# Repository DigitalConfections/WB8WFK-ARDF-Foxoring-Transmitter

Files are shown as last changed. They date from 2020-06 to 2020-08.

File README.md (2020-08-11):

<h1>WB8WFK ARDF Foxoring Transmitter</h1>
<p>This is a simple, inexpensive, transmitter and controller for conducting ARDF Foxoring competitions and for demonstrating ARDF principles. The software project is an Arduino script that builds for and runs on most Arduino-like products, including <a href="https://www.adafruit.com/product/2590">AdaFruit's Metro Mini 328</a>, or <a href="https://www.sparkfun.com/products/11113">SparkFun's Arduino Pro Mini 328</a>, and most any board with an ATMEGA328P processor.</p>

<p>Controller support for all the common ARDF competition formats is provided: Classic, Sprint, and Foxoring.</p>

<h2>Software</h2>
<p>The software is a proper Arduino script that will open and build without warnings or errors in Arduino IDE version 1.8.12 and later. It has also been shown to work with the online <a href="https://create.arduino.cc/editor">Arduino Web Editor</a>. The Arduino IDE can be used to program a device that contains a compatible bootloader. Most Arduino products ship with a bootloader pre-installed.</p>

<p>After being programmed, the controller can be configured via a serial port on the board. An Arduino board that includes a USB-to-Serial converter will allow you to configure the controller with a simple USB cable (standard to micro) connected between a USB port on your computer to one on the Arduino board. Less sophisticated Arduino boards lacking a USB-to-Serial converter will require a special FTDI cable like <a href="https://www.adafruit.com/product/70">AdaFruit's FTDI Serial TTL-232 USB Cable</a>, or <a href="https://www.sparkfun.com/products/9718">SparkFun's FTDI Cable 5V</a>.</p>

<p>The fox-controller software provides an output pin for controlling a transmitter for sending Morse code characters (high = key down; low = key up) and a separate pin that sends the Morse code as audio tones that can be used to drive a speaker. The controller can also provide a sequence of starting-tones prompting competitors to begin a competition, and can thus serve as an electronic starting "gun" for use in ARDF events.</p>

<h3>Serial Commands</h3>
<p>The fox-controller serial interface operates at 57600 baud, and can be accessed using any serial TTY interface program such as PuTTY or Arduino's own Serial Monitor tool. It provides a command prompt > indicating that it is ready to receive any of the following commands.
</p>

<pre><p><b>> CAL [num]</b>  <= <i>* Sets the clock calibration for precise timing</i><br>
<b>> CAL</b>  <= <i>Displays the clock calibration setting</i><br>
<b>> DIP [val]</b>  <= <i>* Sets the competition format, overriding the DIP switch settings</i><br>
<b>> DIP</b>  <= <i>Displays the competition format setting</i><br>
<b>> FAC</b>  <= <i>Sets saved EEPROM values to their original defaults</i><br>
<b>> GO</b>  <= <i>Starts operation from zero seconds, equivalent to pressing the sync button</i><br>
<b>> ID [string]</b>  <= <i>* Sets the callsign that gets sent</i><br>
<b>> ID</b>  <= <i>Displays the saved callsign setting</i><br>
<b>> LED [on|off]</b>  <= <i>* Turns on/off LED pin</i><br>
<b>> LED</b>  <= <i>Displays the LED pin setting</i><br>
<b>> RST</b>  <= <i>Resets the processor</i><br>
<b>> SPD ID [num]</b>  <= <i>* Sets the ID code speed in WPM</i><br>
<b>> SPD</b>  <= <i>Displays the ID code speed setting</i><br>
<b>> STA [on|off]</b>  <= <i>* Turns on/off the starting tones function</i><br>
<b>> STA</b>  <= <i>Displays the starting tones setting</i><br>
<b>> TEM</b>  <= <i>Displays the processor's temperature in C</i><br>
<b>> TXE [on|off]</b>  <= <i>* Turns on/off the transmitter</i><br>
<b>> TXE</b>  <= <i>Displays the transmitter setting</i><br>
<b>> VER</b>  <= <i>Displays the software version number</i></p></pre>

<p>* These values get stored to EEPROM and are retained between power cycles. </p>
<h2>Hardware</h2>
<p>Look in the Hardware folder for all hardware-related documents</p>
<h3>Pinout</h3>

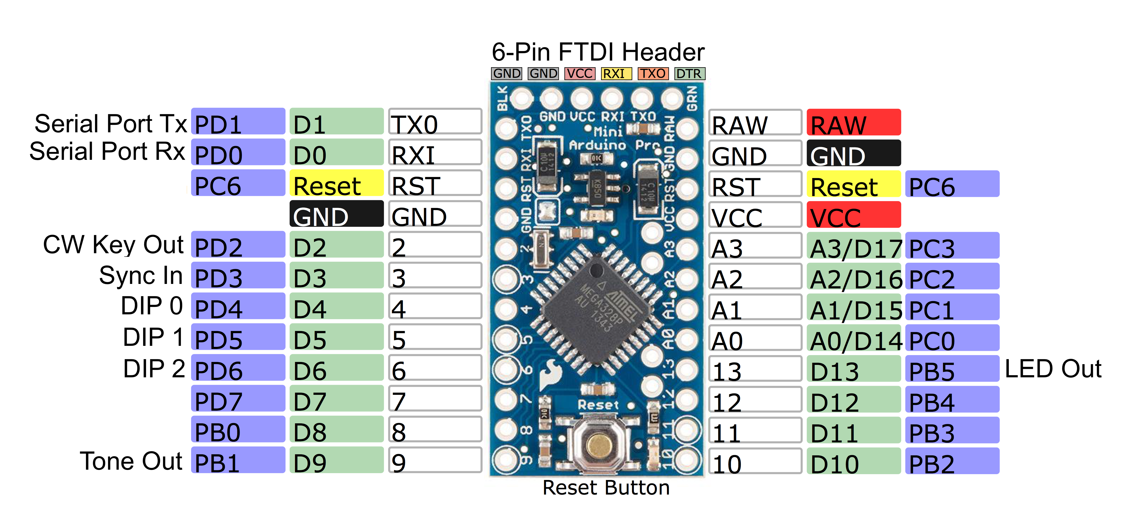
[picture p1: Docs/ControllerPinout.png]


<pre><p><b>PB1 - Board Pin 9  (Output)</b> <= Audio Out (=Gnd when no tone)<br>
<b>PB5 - Board Pin 13 (Output)</b> <= LED On=VCC<br>
<b>PD2 - Board Pin 2  (Output)</b> <= Key/PTT On=VCC<br>
<b>PD3 - Board Pin 3  (Input)</b>  <= Synchronize (mom. switch to Gnd)<br>
<b>PD4 - Board Pin 4  (Input)</b> <= DIP Switch Bit 0 (switch to Gnd)<br>
<b>PD5 - Board Pin 5  (Input)</b> <= DIP Switch Bit 1 (switch to Gnd)<br>
<b>PD6 - Board Pin 6  (Input)</b> <= DIP Switch Bit 2 (switch to Gnd)</p></pre>

<h2>Usage</h2>
<p>The transmitter can be configured using the serial port, or using the DIP switch and sync-button hardware interface. Only a subset of the possible configurations is available when using only the hardware interface. Configuring the DIP setting with a serial port command to anything but CLASSIC BEACON (zero) will disable the hardware DIP switch.</p>
<p>In the table below, default settings are shown in <b>boldface</b>. Serial command arguments may be abbreviated using the first letter of the word. For example: <b>> DIP CLASSIC BEACON</b> can be shortened to <b>> DIP C B</b>.</p>
<p>
    <table>
        <tr>
            <th>Function</th>
            <th>Software Commands</th>
            <th>Hardware Settings</th>
        </tr>
        <tr>
            <td>Homing Beacon</td>
            <td><b>> DIP CLASSIC BEACON</b><br>[Note: the DIP switch must also be set to 0-0-0]</td>
            <td>DIP = 0-0-0</td>
        </tr>
        <tr>
            <td>Classic Fox#1</td>
            <td>> DIP CLASSIC 1<br>> GO</td>
            <td>DIP = 0-0-1<br>Sync to start</td>
        </tr>
        <tr>
            <td>Classic Fox#2</td>
            <td>> DIP CLASSIC 2<br>> GO</td>
            <td>DIP = 0-1-0<br>Sync to start</td>
        </tr>
        <tr>
            <td>Classic Fox#3</td>
            <td>> DIP CLASSIC 3<br>> GO</td>
            <td>DIP = 0-1-1<br>Sync to start</td>
        </tr>
        <tr>
            <td>Classic Fox#4</td>
            <td>> DIP CLASSIC 4<br>> GO</td>
            <td>DIP = 1-0-0<br>Sync to start</td>
        </tr>
        <tr>
            <td>Classic Fox#5</td>
            <td>> DIP CLASSIC 5<br>> GO</td>
            <td>DIP = 1-0-1<br>Sync to start</td>
        </tr>
        <tr>
            <td>Classic Demonstration</td>
            <td>> DIP CLASSIC DEMO</td>
            <td>DIP = 1-1-0</td>
        </tr>
        <tr>
            <td>Foxoring</td>
            <td>> DIP FOXORING</td>
            <td>DIP = 1-1-1</td>
        </tr>
        <tr>
            <td>Spectator Beacon</td>
            <td>> DIP FOXORING SPEC</td>
            <td>N/A</td>
        </tr>
        <tr>
            <td>Sprint Fox Slow #1</td>
            <td>> DIP SPRINT S1</td>
            <td>N/A</td>
        </tr>
        <tr>
            <td>Sprint Fox Slow #2</td>
            <td>> DIP SPRINT S2</td>
            <td>N/A</td>
        </tr>
        <tr>
            <td>Sprint Fox Slow #3</td>
            <td>> DIP SPRINT S3</td>
            <td>N/A</td>
        </tr>
        <tr>
            <td>Sprint Fox Slow #4</td>
            <td>> DIP SPRINT S4</td>
            <td>N/A</td>
        </tr>
        <tr>
            <td>Sprint Fox Slow #5</td>
            <td>> DIP SPRINT S5</td>
            <td>N/A</td>
        </tr>
        <tr>
            <td>Sprint Fox Fast #1</td>
            <td>> DIP SPRINT F1</td>
            <td>N/A</td>
        </tr>
        <tr>
            <td>Sprint Fox Fast #2</td>
            <td>> DIP SPRINT F2</td>
            <td>N/A</td>
        </tr>
        <tr>
            <td>Sprint Fox Fast #3</td>
            <td>> DIP SPRINT F3</td>
            <td>N/A</td>
        </tr>
        <tr>
            <td>Sprint Fox Fast #4</td>
            <td>> DIP SPRINT F4</td>
            <td>N/A</td>
        </tr>
        <tr>
            <td>Sprint Fox Fast #5</td>
            <td>> DIP SPRINT F5</td>
            <td>N/A</td>
        </tr>
        <tr>
            <td>Sprint Demonstration</td>
            <td>> DIP SPRINT DEMO</td>
            <td>N/A</td>
        </tr>
        <tr>
            <td>Starting Tones Generator</td>
            <td>> DIP [any of the above]<br><b>> STA ON</b><br>> GO</td>
            <td>N/A</td>
        </tr>
        <tr>
            <td>Synchronize</td>
            <td>> GO</td>
            <td>Pull sync pin low for at least 1 second<br>Allow sync pin to rise<br>[Must happen within 1 fox cycle after power-on]</td>
        </tr>
    </table>
</p>

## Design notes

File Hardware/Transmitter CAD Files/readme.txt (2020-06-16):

files in this zip are:

1. readme.txt  this file.
2. case_lid.stl the lid for the transmitter case.
3. bottom_half.stl the bottom main part of the case.
4. 80mbase.stl the sub chaassis that the PCB mounts on. Glue inside case.
5. audio_jack_holder.stl  a bracket to hold optional audio jack for tone outputs.
6. 9vbattery_adaptor.stl a test adaptor for testbench testing with a powersupply.

All units are mm

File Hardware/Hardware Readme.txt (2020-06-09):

Boards were ordered from JLCPCP https://jlcpcb.com/

It's important to set up an account and login before uploading the zip file. Failure to do so could result in losing the file from your cart.

Just log in, upload the zip as is (they check the files instantly), select some options and the number of boards you want.

Typical cost for these boards is $25 / 15 boards with no discounts applied.

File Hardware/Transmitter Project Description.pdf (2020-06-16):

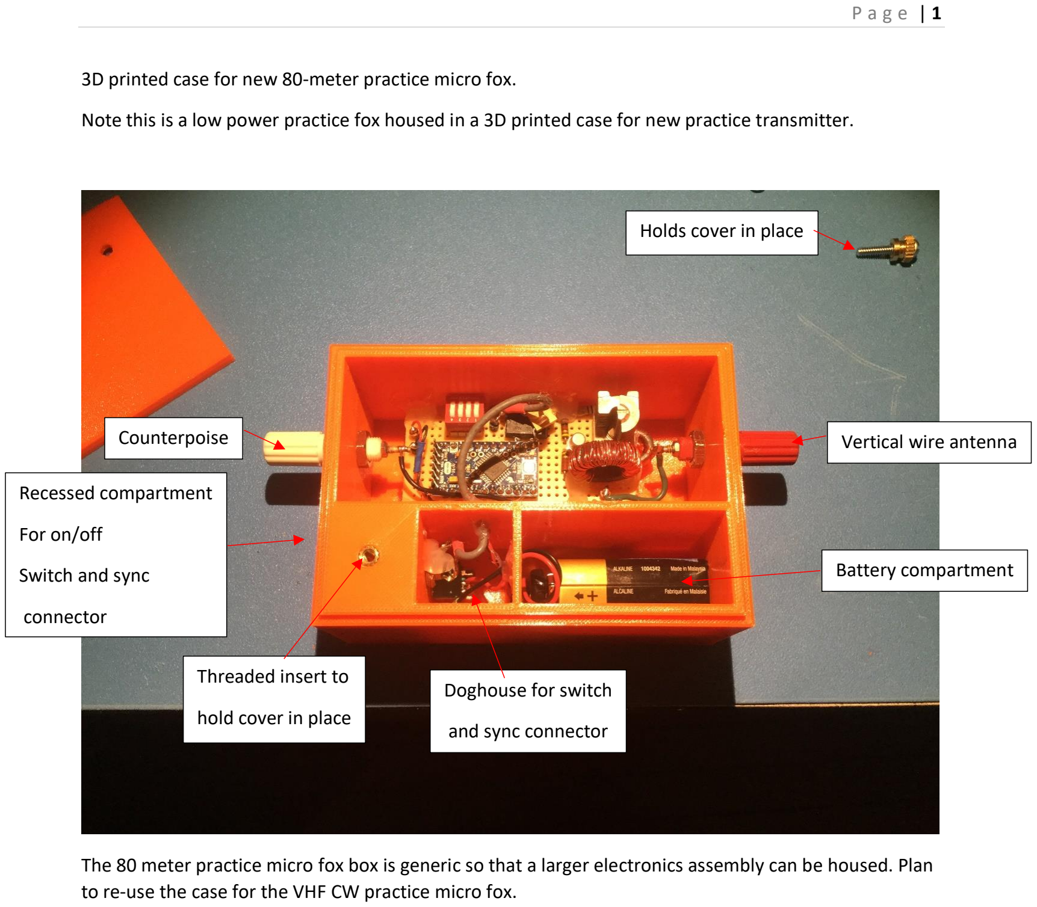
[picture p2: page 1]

P a g e | 1

3D printed case for new 80-meter practice micro fox.

Note this is a low power practice fox housed in a 3D printed case for new practice transmitter.

The 80 meter practice micro fox box is generic so that a larger electronics assembly can be housed. Plan to re-use the case for the VHF CW practice micro fox.

Counterpoise | Vertical wire antenna

Battery compartment

Doghouse for switch

and sync connector

Recessed compartment

For on/off

Switch and sync

connector

Threaded insert to

hold cover in place

Holds cover in place

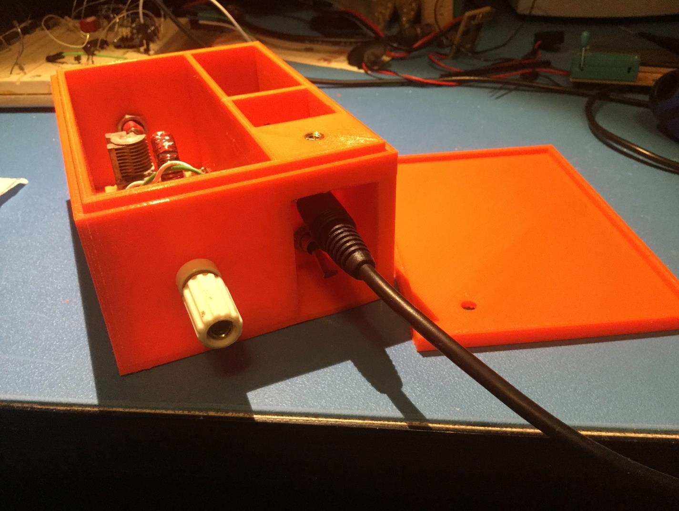
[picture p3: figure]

Here the sync cable is plugged in. Plan to make a 3D cover to slide in and cover the recessed on/off switch and sync compartment

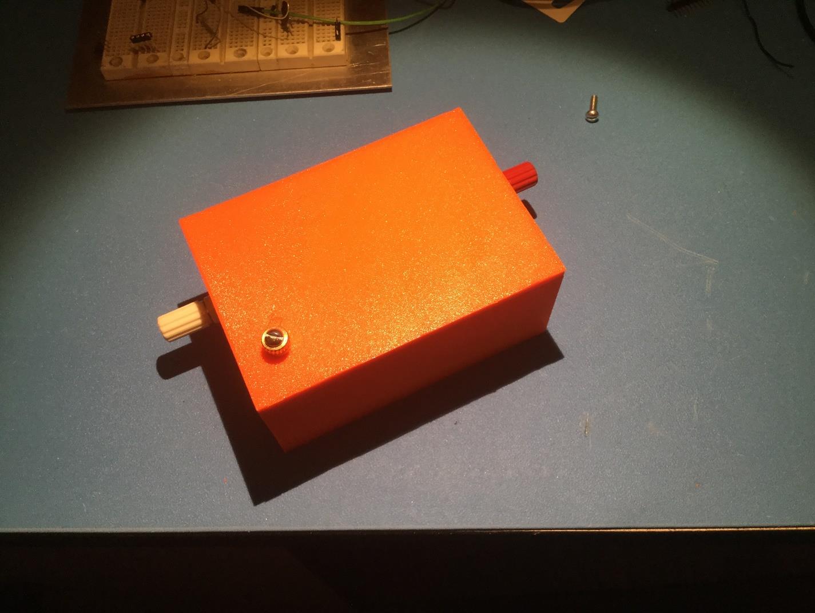
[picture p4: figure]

Here the cover is in place.

The fox Arduino code does the following based on dip switch setting

- Standard 5 transmitter MOE, MOI, MOS, MOH and MO5 one minute on synced via sync connector.
- MO homing beacon mode.
- Practice mode where it cycles through MOE, MOI, MOS, MOH and MO5 from single transmitter for a one transmitter practice session.
- Fox O (beep - beep) mode with one-minute ID.
- Sync input is not a CPU reset its accomplished using an I/O line that checked after power up and after sync operation it no longer checked again until next power cycle. Prevents false resets due to ESD events if a processor reset line is used for sync. ESD is an issue in NM due to our exceptionally low humidity.

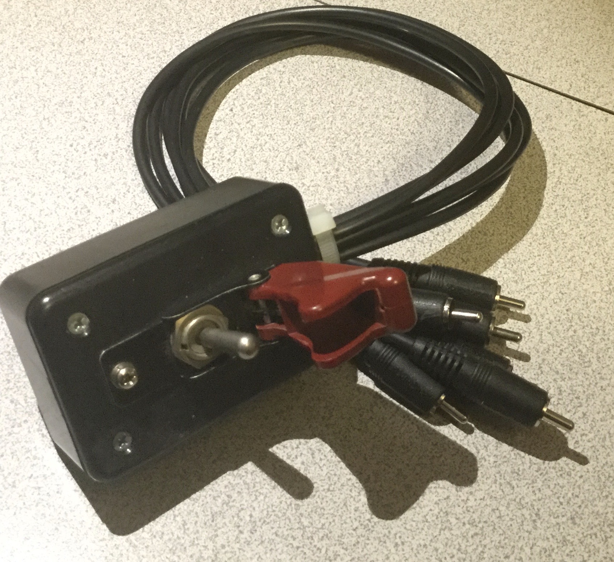
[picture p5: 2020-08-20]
Hardware/sync_switch.jpg

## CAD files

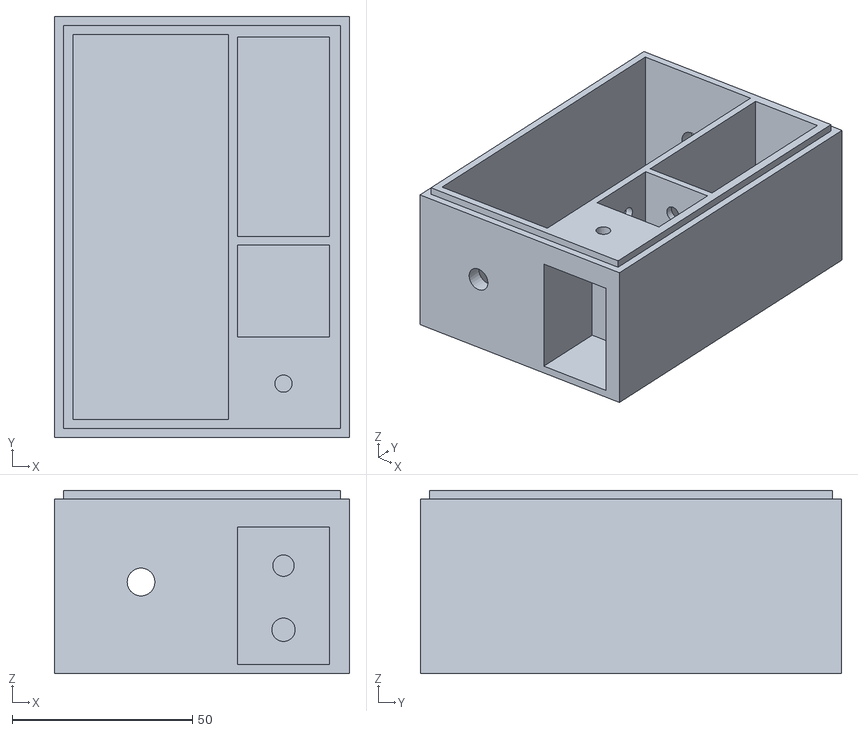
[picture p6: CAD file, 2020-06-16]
Hardware/Transmitter CAD Files/bottom_half.stl
81.8 x 116.8 x 50.8

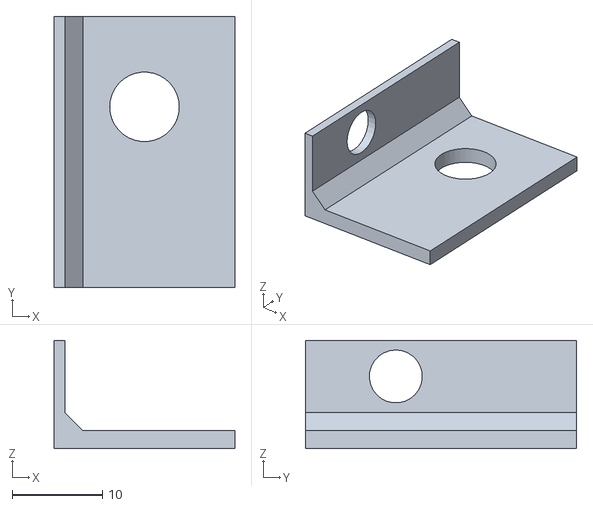
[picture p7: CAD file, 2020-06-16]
Hardware/Transmitter CAD Files/audio_jack_holder.stl
20.0 x 30.0 x 12.0

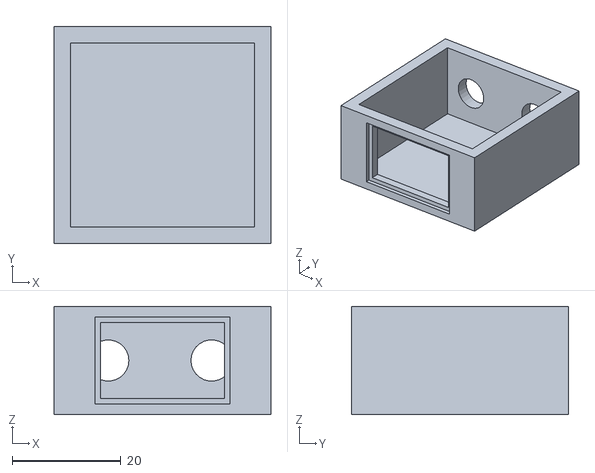
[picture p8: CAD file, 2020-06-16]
Hardware/Transmitter CAD Files/9vbattery_adaptor.stl
40.0 x 40.0 x 20.0

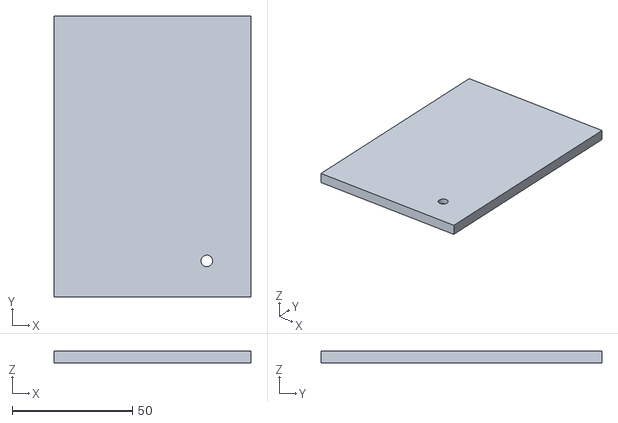
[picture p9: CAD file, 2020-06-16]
Hardware/Transmitter CAD Files/case_lid.stl
81.8 x 116.8 x 5.08

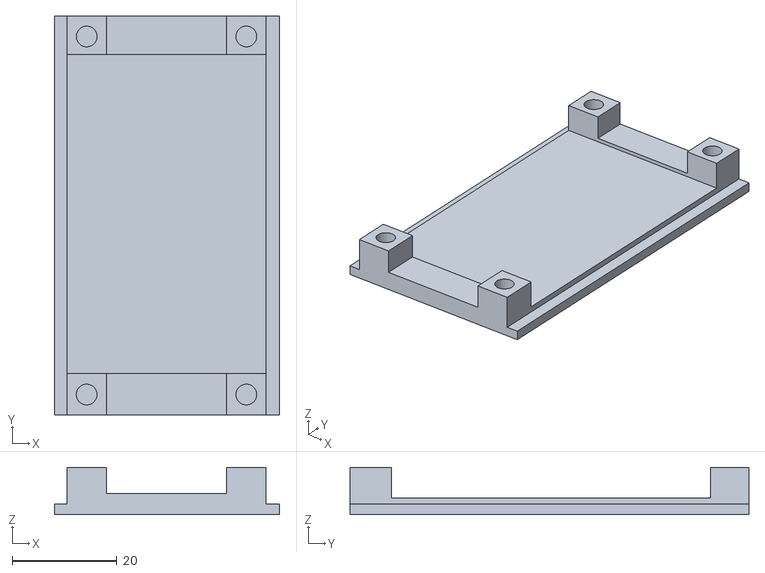
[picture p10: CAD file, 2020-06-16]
Hardware/Transmitter CAD Files/80mbase.stl
43.0 x 76.2 x 9.00

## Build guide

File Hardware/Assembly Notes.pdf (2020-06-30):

## Section 1: Reference graphics

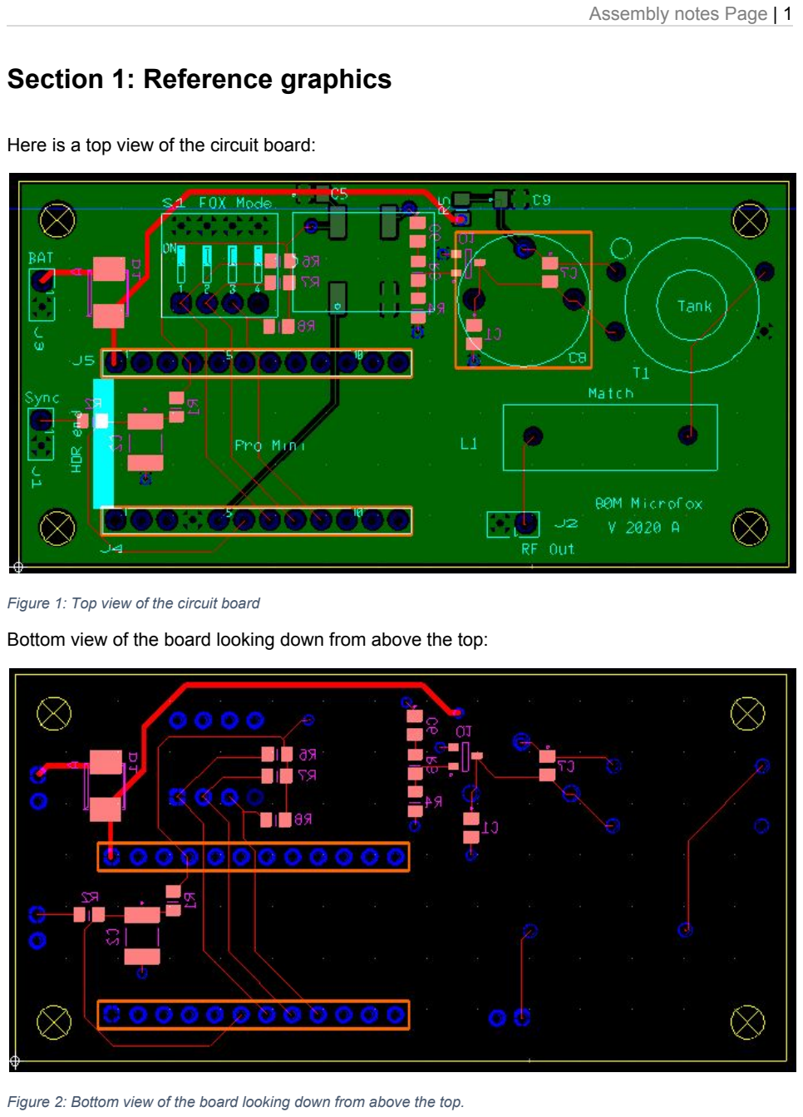
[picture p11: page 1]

Assembly notes Page | 1

Here is a top view of the circuit board:

Figure 1: Top view of the circuit board
Bottom view of the board looking down from above the top:

Figure 2: Bottom view of the board looking down from above the top.

Photo of the bottom of the board showing connection to tone output. This is a feature that was added to provide a start timer function, have audio for demo modes, or for modulation.

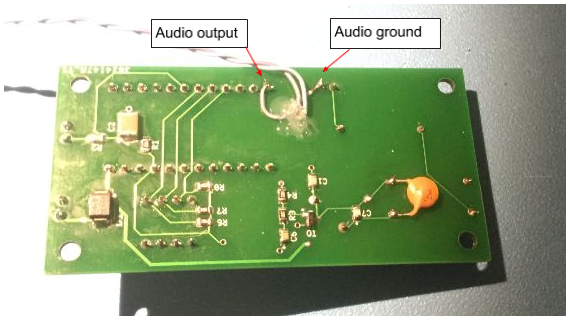
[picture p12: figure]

Figure 3: Bottom of the board showing connections for audio output.

Audio output comes from Pin 9 (PB1) of the pro-mini board. Caution: watch out for ESD damage. If an external amp is used add a series resistance between this net and the audio jack (~1K) to help limit ESD current to a value that the on-chip ESD diodes can handle. If driving an audio speaker directly, watch out for ESD damage from charged cables.

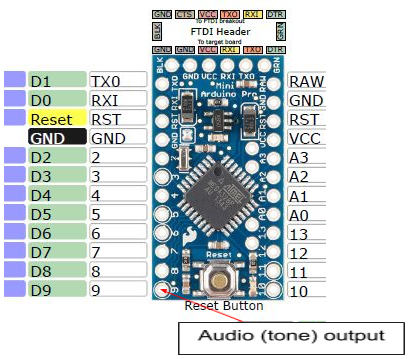
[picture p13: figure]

Figure 4: Audio output from Pro Mini.

## Section 2: General Assembly Notes

After building 5 units here are some things I have seen.

1. It’s best to install the oscillator (U2) first, before installing anything else. This allows free access for soldering to all the pins. Then install the DIP switch.
2. Install the board headers J4 and J5 next. They can then be used as an alignment jig for installing the header pins on the SparkFun Pro Mini. The Pro Mini comes from SparkFun without any headers installed. This will help get into the headers aligned straight up (referenced to the Pro Mini board).
3. Then you can install the balance of all other components in any order.

Some other notes: There have been software updates that allow the removal of some components. For example, if you are using the DIP switch there is no longer the need for using R6, R7, and R8 as the software has a compile switch that enables internal chip pull-ups. Yes, fewer parts! The R1 pull-up for the sync switch can also be omitted if the compile switch is enabled.

Even greater parts reduction is possible. The software allows setting the fox modes without the need of the DIP switch. If you will only be configuring the transmitter via its serial port, then you don’t need the DIP switch at all. The serial command “> DIP 0” (the default setting) instructs the software to use the DIP switch.

## Notes On The 3D-Printed Case

I mounted my on/off switch so that ON is down. The rationale behind this is that it makes it harder to accidentally turn off the unit after synchronizing.

The following 3D-printed base plate holds the board. It uses 4-40 inserts that are inserted using a soldering iron set to a reduced temperature (~200 deg C).

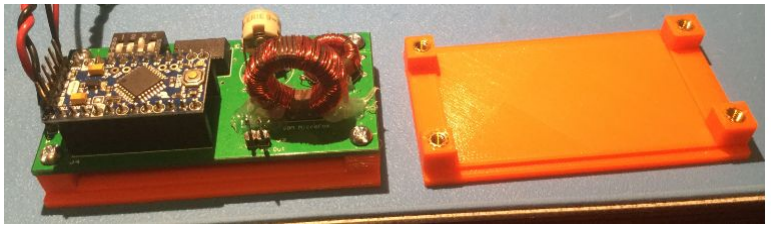
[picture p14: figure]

Figure 5: Board and sub-plate.

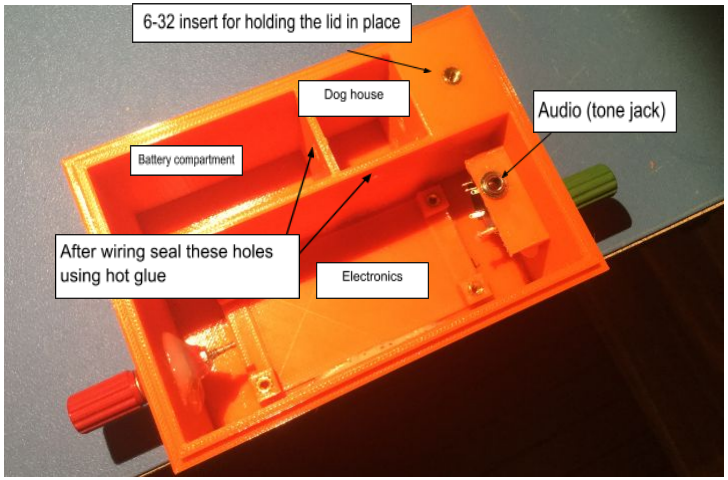
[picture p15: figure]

Figure 6: Sub-plate installed in the case.
The sub-plate was glued in place using Gorilla Glue. Note the audio jack that was installed for providing tone output from Pin 9. The red banana is for the vertical antenna wire and the green one is used for the two antenna counterpoise wires. Note: use hot glue to seal the two through-case holes to keep water out of the battery and electronics compartments as it could get into the dog house form the sync connector.

### Controls Installation

Here are the locations for the sync input and on/off switch:

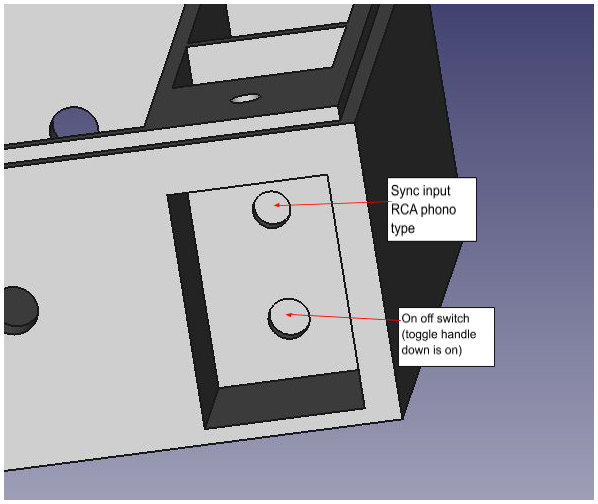
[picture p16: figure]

### Calibration

Due to the broad tolerance of the ceramic resonator used for the clock oscillator, Pro Mini boards exhibit significant frequency drift over time. I have observed tens of kHz differences in the 16 MHz master oscillator frequency. The software allows setting a calibration value to correct the 1-second timer to account for the clock frequency drift.

It is important to perform a calibration after the board is installed in the case, as I noticed that bending (putting the board under stress) can shift the oscillator frequency. So, perform the calibration after everything is mounted and wired in place.

Calibration can be performed using an accurately-calibrated radio receiver capable of receiving at 16 MHz or using an oscilloscope or frequency counter capable of accurately measuring the frequency of a 600 Hz square wave.

Receiver Method

Use an HF receiver and a small loop sensor. With the receiver in CW mode (narrow bandwidth setting) zero beat the master oscillator signal and note the frequency indicated by the radio.

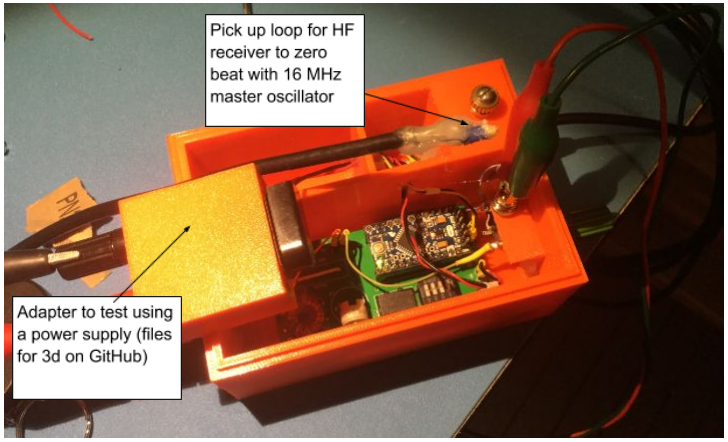
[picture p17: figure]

Figure 7: Receiver calibration method.
After obtaining the frequency of the oscillator, use the following script, or manually compute the calibration value using the equations in the script. The script is written in SCILAB, an open-source version of MATLAB scientific scripting software.

To download SCILAB go to https://www.scilab.org/

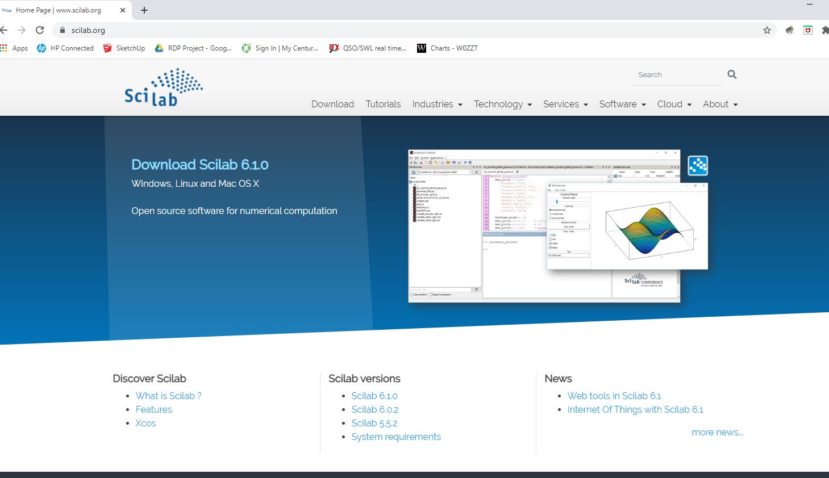
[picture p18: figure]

The calibration script starts below.

clc;
//
// Oscillator calibration calculator
//
// Enter measured frequency of Oscillator in MHz using CW receiver to zero beat
mprintf("Enter frequency of the Oscillator in MHZ?\n"); FREQ = mscanf("%f");
FREQ_for_calc_IN_HZ = FREQ*1E6;
//
//
CALIBRATE = (FREQ_for_calc_IN_HZ/1024)-1; //

// Now display it for printing a label
// Cut and paste the output into Notepad and print the label //
mprintf('Oscillator Frequency = %2.5f MHz \n',FREQ); mprintf('Calibration = %1.3f \n',CALIBRATE); mprintf('Calibration = %d \n',round(CALIBRATE)); mprintf('Use CAL command CAL<sp>%d to enter n',round(CALIBRATE));

After running the script or manually computing the calibration value, use the > CAL serial command to enter the calibration into non-volatile storage. It is recommended to print a calibration tag and tape it inside the unit. I copy the output from the script into a Notepad document and print it.

Oscilloscope or Frequency Counter Method

Enable the compile switch in defs.h to turn on the calibration signal on Pin 11 (PB3). Compile the project software and install it in the transmitter to be calibrated.

Measure the frequency of the signal on Pin 11. It should be close to 601 Hz. The calibration value is derived using the following formula:

CAL = 26f -1

Where f is the frequency measured on Pin 11.

Use the > CAL nnnnn serial command to apply the clock calibration value.

### 3D box parts

Here are the components that make up the 3D printed case

The following files are in the GitHub repository for this project.

1. case_lid.stl the lid for the transmitter case.
2. bottom_half.stl the bottom main part of the case.
3. 80mbase.stl the sub-chassis that the PCB mounts on. Glue to the inside of the case.
4. audio_jack_holder.stl a bracket to hold optional audio jack for tone output.
5. 9vbattery_adaptor.stl an optional test adaptor for bench testing with a power supply.

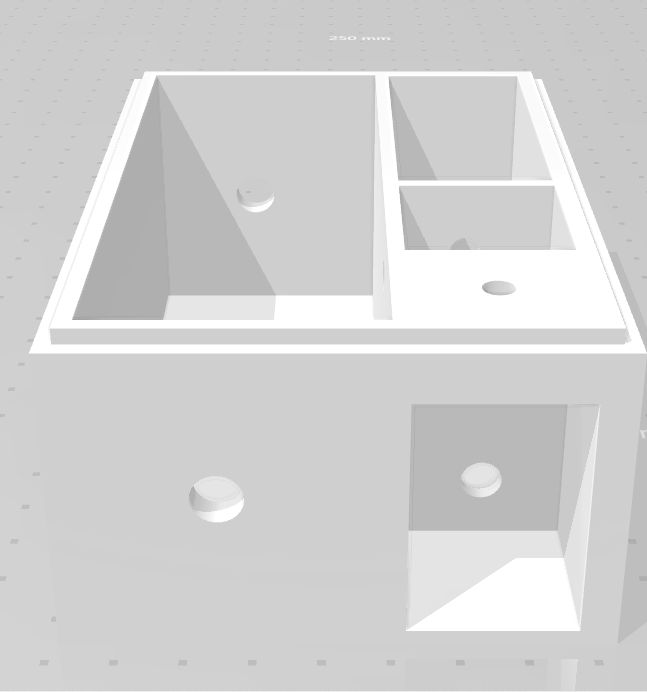
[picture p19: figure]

Figure 8: Main case.

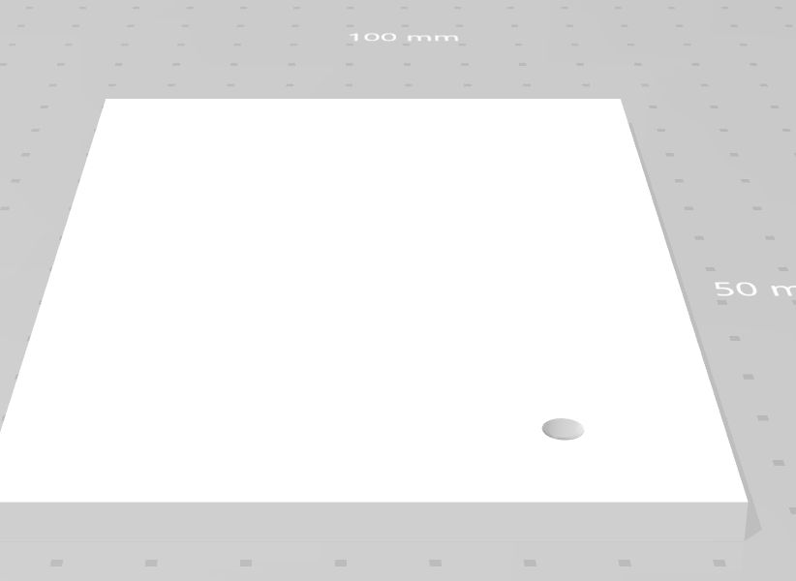
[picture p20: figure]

Figure 9: Case lid.

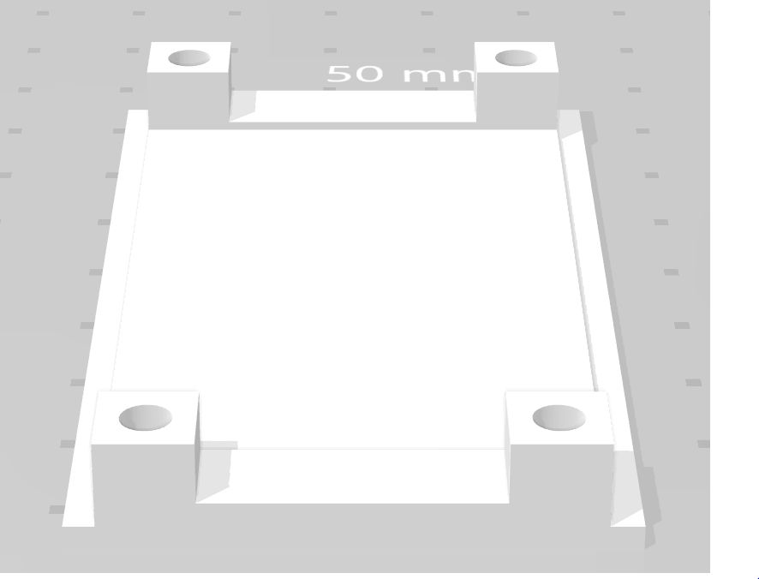
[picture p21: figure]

Figure 10: The sub-base for mounting the PCB.

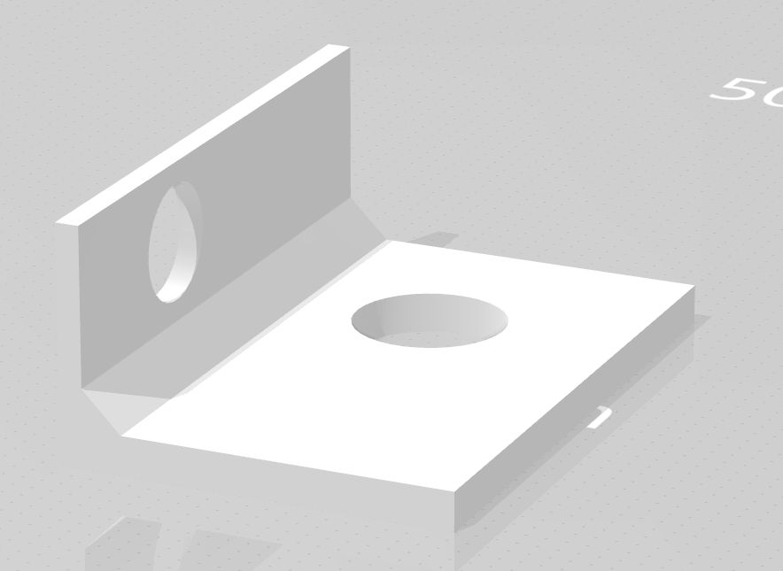
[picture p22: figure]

Figure 11: Audio jack holder.

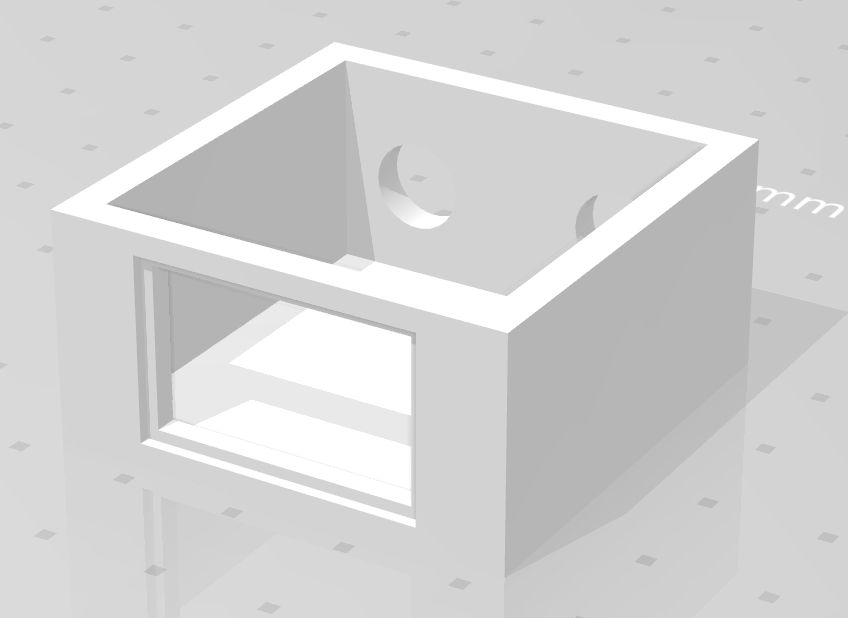
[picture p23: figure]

Figure 12: Test jig for testing without batteries.
Note: for the test jig the battery connector was harvested from expired 9-volt batteries.

## Section 3: Other Notes

Battery Installation Tips

To make it easy to remove the battery from the battery cavity, make a tape tag as shown below. Otherwise, the battery may be somewhat tricky to remove.

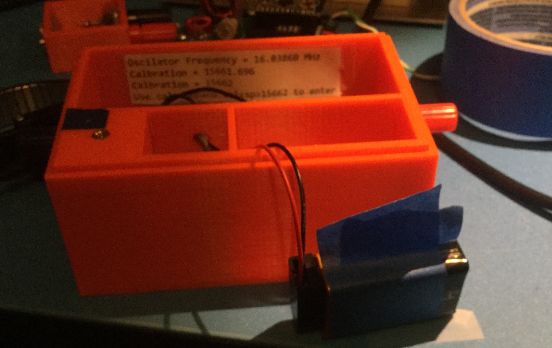
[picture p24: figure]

Figure 13: Tag on battery before installation.

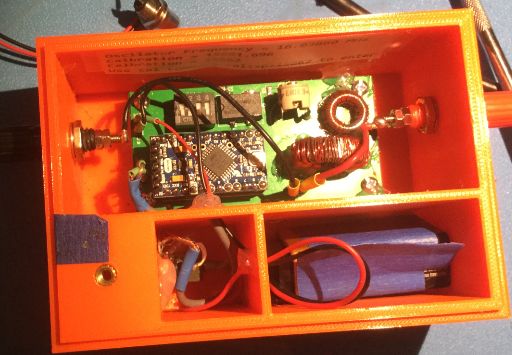
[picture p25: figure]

Figure 14: Battery installed.
Note about syncing and transport

The transmitter was designed to run without an antenna load attached. So, after syncing, just put the active transmitter(s) into a backpack. You can continue to monitor foxes as you place them in the field. Foxes in the backpack lacking antennas, and those placed on the course, can all be monitored to confirm that all is well during field installation.

Note about antennas

The original transmitter was designed to work with a 25-foot vertical wire and counterpoise. If your antenna provides matching then you should be able to omit L1 (match). In that case install an insulated jumper in place of L1.

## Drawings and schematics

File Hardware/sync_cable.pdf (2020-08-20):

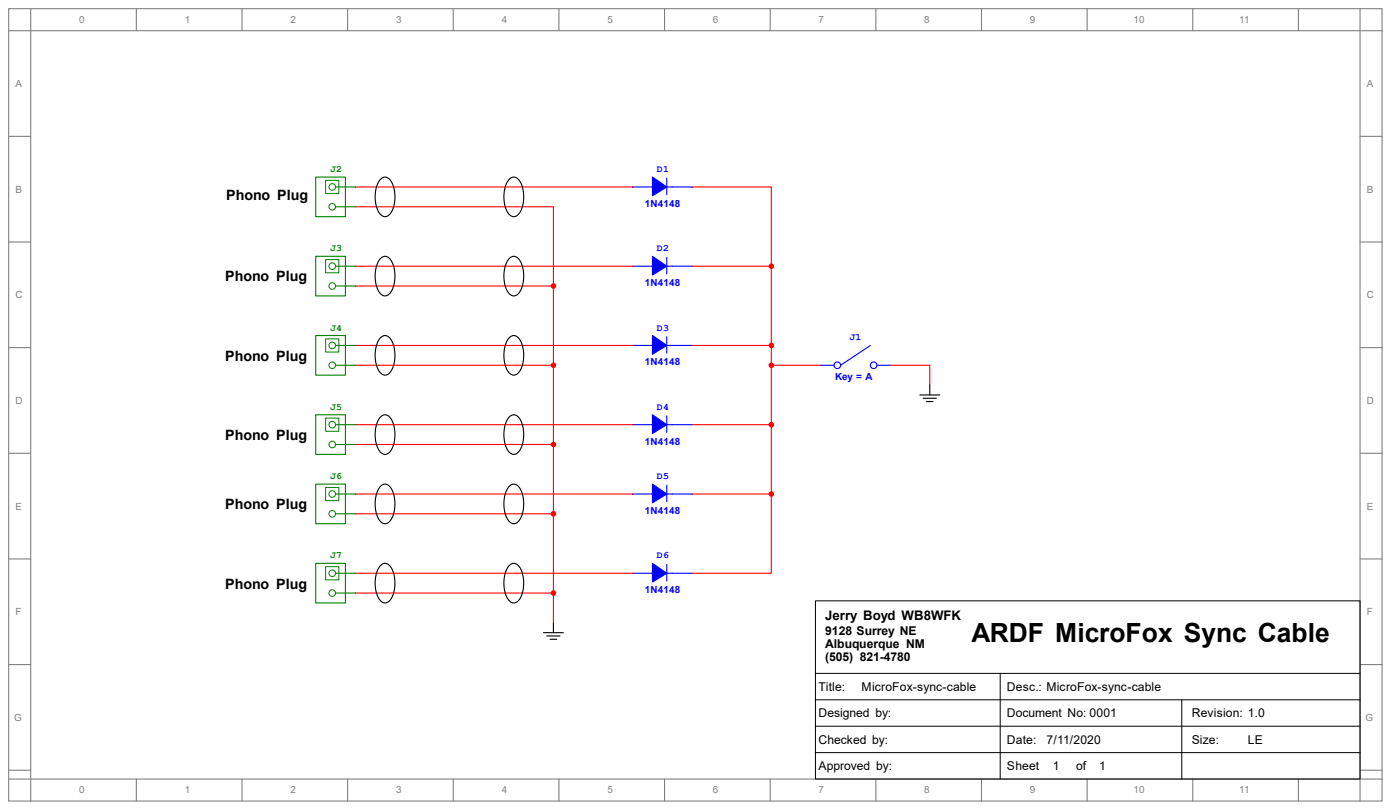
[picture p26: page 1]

ARDF MicroFox Sync Cable

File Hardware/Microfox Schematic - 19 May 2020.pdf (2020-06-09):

## Wire Antenna

# 9V batt

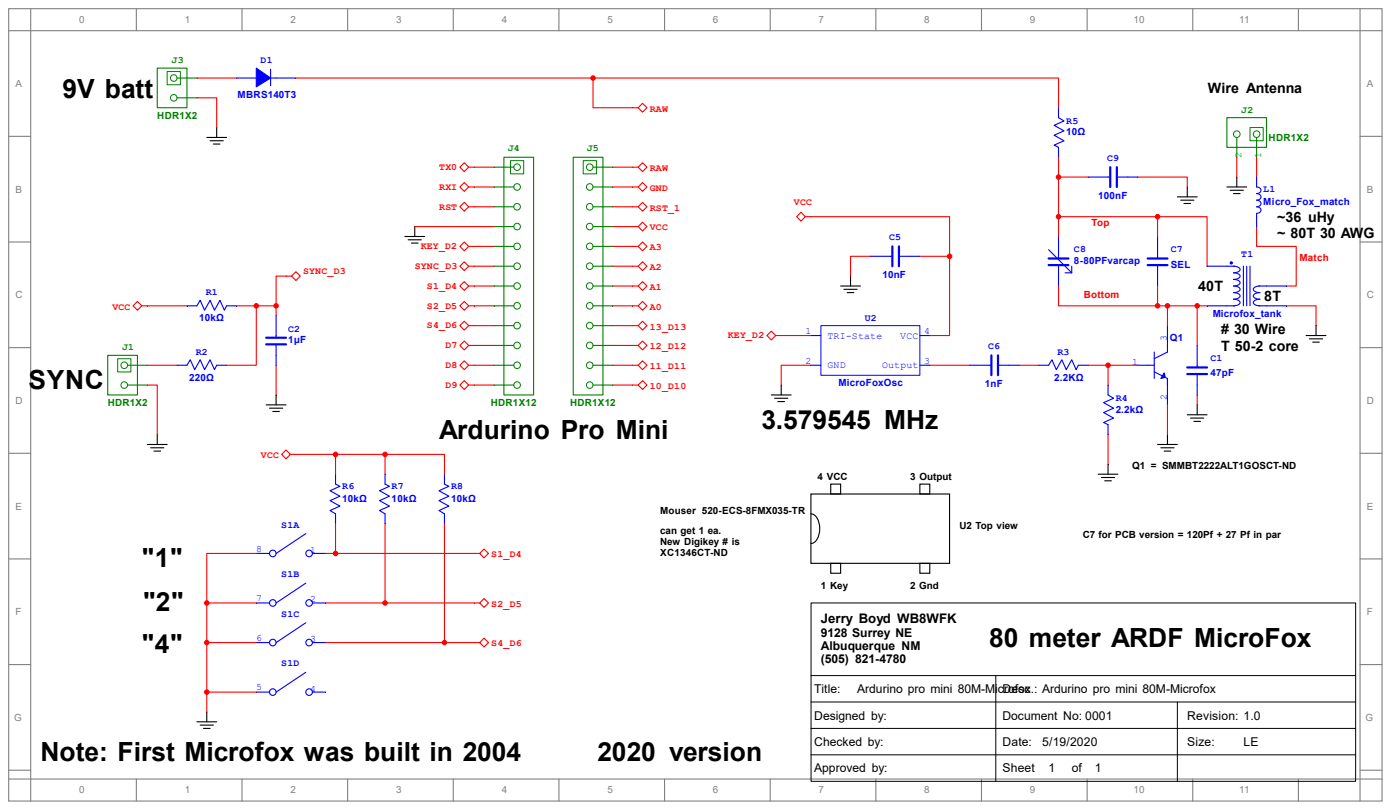
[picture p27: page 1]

C7 for PCB version = 120Pf + 27 Pf in par

Ardurino pro mini 80M-Microfox

Note: First Microfox was built in 2004

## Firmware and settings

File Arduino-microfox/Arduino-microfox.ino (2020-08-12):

/*
 *  MIT License
 *
 *  Copyright (c) 2020 DigitalConfections
 *
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
 *  THE SOFTWARE IS PROVIDED "AS IS", WITHOUT WARRANTY OF ANY KIND, EXPRESS OR
 *  IMPLIED, INCLUDING BUT NOT LIMITED TO THE WARRANTIES OF MERCHANTABILITY,
 *  FITNESS FOR A PARTICULAR PURPOSE AND NONINFRINGEMENT. IN NO EVENT SHALL THE
 *  AUTHORS OR COPYRIGHT HOLDERS BE LIABLE FOR ANY CLAIM, DAMAGES OR OTHER
 *  LIABILITY, WHETHER IN AN ACTION OF CONTRACT, TORT OR OTHERWISE, ARISING FROM,
 *  OUT OF OR IN CONNECTION WITH THE SOFTWARE OR THE USE OR OTHER DEALINGS IN THE
 *  SOFTWARE.
 */
/*
 * Microfox Arduino nano version. Converted from PIC C November 2019
 * Jerry Boyd WB8WFK
 * This controller will replace the Albuquerque VHF and HF microfox pic based controller
 *
 * */


#include "defs.h"
#include "linkbus.h"
#include "morse.h"
#include <avr/wdt.h>

#if COMPILE_FOR_ATMELSTUDIO7
#include <avr/io.h>
#include <avr/eeprom.h>
#include <string.h>
#include <ctype.h>
#include <stdio.h>
#include <stdlib.h>
#include <math.h>
#include "delay.h"
#include "ardooweeno.h"
#endif  /* COMPILE_FOR_ATMELSTUDIO7 */

#define MAX_PATTERN_TEXT_LENGTH 20
#define TEMP_STRING_LENGTH (MAX_PATTERN_TEXT_LENGTH + 10)

volatile int32_t g_seconds_since_sync = 0;  /* Total elapsed time counter */
volatile FoxType g_fox          = BEACON;   /* Sets Fox number not set by ISR. Set in startup and checked in main. */
volatile int g_active           = 0;        /* Disable active. set and clear in ISR. Checked in main. */

volatile int g_on_the_air       = 0;        /* Controls transmitter Morse activity */
volatile int g_code_throttle    = 0;        /* Adjusts Morse code speed */
const char g_morsePatterns[][6] = { "MO ", "MOE ", "MOI ", "MOS ", "MOH ", "MO5 ", "", "5", "S", "ME", "MI", "MS", "MH", "M5", "OE", "OI", "OS", "OH", "O5" };
volatile BOOL g_callsign_sent = FALSE;

volatile BOOL g_blinky_time = FALSE;

volatile int g_on_air_interval = 0;
volatile int g_fox_seconds_into_interval = 0;
volatile int g_fox_counter = 1;
volatile int g_number_of_foxes = 0;
volatile BOOL g_fox_transition = FALSE;
volatile int g_fox_id_offset = 0;
volatile int g_id_interval = 0;
volatile BOOL g_time_to_ID = FALSE;
volatile int g_startclock_interval = 60;
volatile int g_fox_tone_offset = 1;

volatile BOOL g_audio_tone_state = FALSE;
volatile uint8_t g_lastSeconds = 0x00;
volatile int16_t g_sync_pin_timer = 0;
volatile BOOL g_sync_pin_stable = FALSE;
volatile BOOL g_sync_enabled = TRUE;

#if !COMPILE_FOR_ATMELSTUDIO7
	FoxType operator++ (volatile FoxType &orig, int)
	{
		orig = static_cast < FoxType > (orig + 1);  /* static_cast required because enum + int -> int */
		if(orig > INVALID_FOX)
		{
			orig = INVALID_FOX;
		}
		return( orig);
	}

	FoxType operator += (volatile FoxType &a, int b)
	{
		a = static_cast < FoxType > (a + b);    /* static_cast required because enum + int -> int */
		return( a);
	}
 #endif  /* COMPILE_FOR_ATMELSTUDIO7 */


/***********************************************************************
 * Global Variables & String Constants
 *
 * Identify each global with a "g_" prefix
 * Whenever possible limit globals' scope to this file using "static"
 * Use "volatile" for globals shared between ISRs and foreground
 ************************************************************************/
static uint8_t EEMEM ee_interface_eeprom_initialization_flag = EEPROM_UNINITIALIZED;
static char EEMEM ee_stationID_text[MAX_PATTERN_TEXT_LENGTH + 1];
static uint8_t EEMEM ee_id_codespeed;
static uint16_t EEMEM ee_clock_calibration;
static uint8_t EEMEM ee_override_DIP_switches;
static uint8_t EEMEM ee_enable_LEDs;
static int16_t EEMEM ee_temp_calibration;
static uint8_t EEMEM ee_enable_start_timer;
static uint8_t EEMEM ee_enable_transmitter;

static char g_messages_text[2][MAX_PATTERN_TEXT_LENGTH + 1] = { "\0", "\0" };
static volatile uint8_t g_id_codespeed = EEPROM_ID_CODE_SPEED_DEFAULT;
static volatile uint8_t g_pattern_codespeed = EEPROM_PATTERN_CODE_SPEED_DEFAULT;
static volatile uint16_t g_time_needed_for_ID = 0;
static volatile uint16_t g_clock_calibration = EEPROM_CLOCK_CALIBRATION_DEFAULT;
static volatile int16_t g_temp_calibration = EEPROM_TEMP_CALIBRATION_DEFAULT;
static volatile uint8_t g_override_DIP_switches = EEPROM_OVERRIDE_DIP_SW_DEFAULT;
static volatile uint8_t g_enable_LEDs;
static volatile uint8_t g_enable_start_timer;
static volatile uint8_t g_enable_transmitter;

static char g_tempStr[TEMP_STRING_LENGTH] = { '\0' };
static volatile uint8_t g_LEDs_Timed_Out = FALSE;
/*
 * Function Prototypes
 */
void handleLinkBusMsgs(void);
void initializeEEPROMVars(BOOL resetAll);
float getTemp(void);
uint16_t readADC();
void setUpTemp(void);
void sendMorseTone(BOOL onOff);
void playStartingTone(uint8_t toneFreq);
void wdt_set(WDReset resetType);
void doSynchronization(void);
void setupForFox(void);
void softwareReset(void);

#if USE_WDT_RESET
uint8_t mcusr_copy __attribute__ ((section (".noinit")));
void disable_wdt(void) \
     __attribute__((naked)) \
     __attribute__((section(".init3")));
void disable_wdt(void) {
  mcusr_copy = MCUSR;
  MCUSR = 0x00;
  wdt_disable();
}
#endif // USE_WDT_RESET


#if COMPILE_FOR_ATMELSTUDIO7
	void loop(void);
	int main(void)
#else
	void setup()
#endif  /* COMPILE_FOR_ATMELSTUDIO7 */
{
	initializeEEPROMVars(FALSE);
	setUpTemp();

	cli();                          /*stop interrupts for setup */

	/* set pins as outputs */
	pinMode(PIN_LED, OUTPUT);       /* The amber LED: This led blinks when off cycle and blinks with code when on cycle. */
	digitalWrite(PIN_LED, OFF);
	pinMode(PIN_MORSE_KEY, OUTPUT); /* This pin is used to control the KEY line to the transmitter only active on cycle. */
	digitalWrite(PIN_MORSE_KEY, OFF);
	pinMode(PIN_AUDIO_OUT, OUTPUT);
	digitalWrite(PIN_AUDIO_OUT, OFF);

	/* Set unused pins as outputs pulled high */
	pinMode(PIN_UNUSED_7, INPUT_PULLUP);
	pinMode(PIN_UNUSED_8, INPUT_PULLUP);
	pinMode(PIN_UNUSED_10, INPUT_PULLUP);
	pinMode(PIN_UNUSED_12, INPUT_PULLUP);
	pinMode(A0, INPUT_PULLUP);
	pinMode(A1, INPUT_PULLUP);
	pinMode(A2, INPUT_PULLUP);
	pinMode(A3, INPUT_PULLUP);
#if !CAL_SIGNAL_ON_PD3
		pinMode(PIN_CAL_OUT, INPUT_PULLUP);
#endif

	/* set timer1 interrupt at 1Hz */
	TCCR1A = 0; /* set entire TCCR1A register to 0 */
	TCCR1B = 0; /* same for TCCR1B */
	TCNT1 = 0;  /*initialize counter value to 0 */

/* Set compare match register for 1hz increments
 ************************************************************
 ** USE THIS TO CALIBRATE FOR BOARD PROCESSOR CLOCK ERROR
 ************************************************************/
	/* first testing found bad drift relative to a gps stable clock (iphone timer) is was 10 seconds in about 50 minutes
	 * Today I measured the Arduino nano 16 Mhz clock and it was 16.050 MHz. Yes 50 Khz high!!
	 * OCR1A = 15624;// = (16*10^6) / (1*1024) - 1 (must be <65536)    //was 15624 for 16.000 MHz on center frequency clock
	 * OCR1A = 15672;// = (16.043*10^6) / (1*1024) - 1 (must be <65536)   //15672 computed for + 16.050 MHz off frequency clock board 4
	 * OCR1A = 15661;// = (16.0386*10^6) / (1*1024) - 1 (must be <65536)   //15661 computed for + 16.0386 MHz off frequency clock board 3 */
/*	OCR1A = 15629;/ * = (16.006*10^6) / (1*1024) - 1 (must be <65536)   //15629 computed for + 16.006 MHz off frequency clock board 3 * / */
	OCR1A = g_clock_calibration;

/* turn on CTC mode */
	TCCR1B |= (1 << WGM12);
/* Set CS11 bit for 1024 prescaler */
	TCCR1B |= (1 << CS12) | (1 << CS10);
/* enable timer compare interrupt */
	TIMSK1 |= (1 << OCIE1A);

	/**
	 * TIMER2 is for periodic interrupts to drive Morse code generation */
	/* Reset control registers */
	TCCR2A = 0;
	TCCR2B = 0;
	TCCR2A |= (1 << WGM21);                             /* set Clear Timer on Compare Match (CTC) mode with OCR2A setting the top */
#if CAL_SIGNAL_ON_PD3
		pinMode(PIN_CAL_OUT, OUTPUT);                   /* 601Hz Calibration Signal */
		TCCR2A |= (1 << COM2A0);                        /* Toggle OC2A (PB3) on compare match */
#endif /* CAL_SIGNAL_ON_PD3 */
	TCCR2B |= (1 << CS22) | (1 << CS21) | (1 << CS20);  /* 1024 Prescaler */

	OCR2A = 0x0C;                                       /* set frequency to ~300 Hz (0x0c) */
	OCR2B = 0x00;
	/* Use system clock for Timer/Counter2 */
	ASSR &= ~(1 << AS2);
	/* Reset Timer/Counter2 Interrupt Mask Register */
	TIMSK2 = 0;
	TIMSK2 |= (1 << OCIE2B);    /* Output Compare Match B Interrupt Enable */

	/* Timer 0 is for audio Start tone generation and control
	 * Note: Do not use millis() or DELAY() after TIMER0 has been reconfigured here! */
	TCCR0A = 0x00;
	TCCR0A |= (1 << WGM01);     /* Set CTC mode */
	TCCR0B = 0x00;
	TCCR0B |= (1 << CS02);      /* Prescale 256 */
	OCR0A = DEFAULT_TONE_FREQUENCY;
	TIMSK0 = 0x00;
	TIMSK0 |= (1 << OCIE0A);

	/* Sync button pin change interrupt */
	PCMSK2 = 0x00;
	PCMSK2 = (1 << PCINT19);    /* Enable PCINT19 */
	PCICR = 0x00;
	PCICR = (1 << PCIE2);       /* Enable pin change interrupt 2 */

	sei();                      /* Enable interrupts */

	linkbus_init(BAUD);         /* Start the Link Bus serial comms */

	setupForFox();

	lb_send_string((char*)"\n\nStored Data:\n", TRUE);
	sprintf(g_tempStr, "  ID: %s\n", g_messages_text[STATION_ID]);
	lb_send_string(g_tempStr, TRUE);
	sprintf(g_tempStr, "  CAL: %u\n", g_clock_calibration);
	lb_send_string(g_tempStr, TRUE);
	sprintf(g_tempStr, "  DIP: %u\n", g_override_DIP_switches);
	lb_send_string(g_tempStr, TRUE);
	sprintf(g_tempStr, "  LED: %s\n", g_enable_LEDs ? "ON" : "OFF");
	lb_send_string(g_tempStr, TRUE);
	sprintf(g_tempStr, "  STA: %s\n", g_enable_start_timer ? "ON" : "OFF");
	lb_send_string(g_tempStr, TRUE);
	sprintf(g_tempStr, "  TXE: %s\n", g_enable_transmitter ? "ON" : "OFF");
	lb_send_string(g_tempStr, TRUE);
	lb_send_NewPrompt();

#if COMPILE_FOR_ATMELSTUDIO7
		while(1)
		{
			loop();
		}
#endif  /* COMPILE_FOR_ATMELSTUDIO7 */
}/*end setup */

/***********************************************************************
 * Pin Change Interrupt 2 ISR
 *
 * Handles SYNC pin operation
 *
 ************************************************************************/
ISR(PCINT2_vect)
{
	BOOL pinVal = digitalRead(PIN_SYNC);

	if(pinVal)  /* Sync is high */
	{
		if(g_sync_pin_stable)
		{
			doSynchronization();
		}
	}

	g_sync_pin_timer = 0;
}
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
void loop()
{
	static int time_for_id = 99;
	static BOOL id_set = TRUE;
	static BOOL proceed = FALSE;

	/**************************************
	* The watchdog must be petted periodically to keep it from barking
	**************************************/
	cli(); wdt_reset(); /* HW watchdog */ sei();

	handleLinkBusMsgs();

	if(!g_on_the_air || proceed)
	{
		proceed = FALSE;

		/* Choose the appropriate Morse pattern to be sent */
		if(g_fox == FOX_DEMO)
		{
			strcpy(g_messages_text[PATTERN_TEXT],g_morsePatterns[g_fox_counter]);
		}
		else if(g_fox == SPRINT_DEMO)
		{
			strcpy(g_messages_text[PATTERN_TEXT],g_morsePatterns[g_fox_counter + 8]);
		}
		else
		{
			strcpy(g_messages_text[PATTERN_TEXT],g_morsePatterns[g_fox]);
		}

		/* At the appropriate time set the pattern to be sent and start transmissions */
		if((g_fox == FOX_DEMO) || (g_fox == SPRINT_DEMO) || (g_fox == BEACON) || (g_fox == FOXORING) || (g_fox == SPECTATOR) || (g_fox == (g_fox_counter + g_fox_id_offset)))
		{
			BOOL repeat = TRUE;
			g_code_throttle = THROTTLE_VAL_FROM_WPM(g_pattern_codespeed);
			makeMorse(g_messages_text[PATTERN_TEXT],&repeat,NULL);

			if(g_time_to_ID || (g_id_interval <= g_on_air_interval))
			{
				time_for_id = g_on_air_interval - (500 + timeRequiredToSendStrAtWPM(g_messages_text[STATION_ID],g_id_codespeed)) / 1000;
				g_time_to_ID = FALSE;
			}
			else
			{
				time_for_id = g_on_air_interval + 99;   /* prevent sending ID */
			}

			id_set = FALSE;
			g_on_the_air = TRUE;
			g_callsign_sent = FALSE;
			g_fox_transition = FALSE;
			g_fox_tone_offset = g_fox_counter;
		}
		else
		{
			if(!g_LEDs_Timed_Out)   /* below will flash LED when off cycle for a heartbeat indicator */
			{
				if(g_blinky_time)
				{
					if(!g_sync_pin_stable)
					{
						digitalWrite(PIN_LED,OFF);
					}
				}
				else
				{
					digitalWrite(PIN_LED,ON);
				}
			}
		}
	}
	else
	{
		if(!id_set && (g_fox_seconds_into_interval == time_for_id)) /* Send the call sign at the right time */
		{
			g_code_throttle = THROTTLE_VAL_FROM_WPM(g_id_codespeed);
			BOOL repeat = FALSE;
			makeMorse(g_messages_text[STATION_ID],&repeat,NULL);
			id_set = TRUE;
			g_callsign_sent = FALSE;
		}
		else if((g_fox >= SPRINT_S1) && (g_fox <= SPRINT_DEMO))
		{
			if(g_fox_transition)
			{
				g_fox_transition = FALSE;
				g_on_the_air = FALSE;
				proceed = TRUE;
			}
		}

		if((g_fox == FOX_DEMO) || (g_fox == SPRINT_DEMO))
		{
			if((g_callsign_sent) && g_fox_transition)   /* Ensure we've begun the next minute before proceeding */
			{
				proceed = TRUE;
			}
		}
		else if((g_fox == BEACON) || (g_fox == FOXORING) || (g_fox == SPECTATOR))   /* Proceed as soon as the callsign has been sent */
		{
			if(g_callsign_sent)
			{
				proceed = TRUE;
			}
		}
		else if((g_fox >= SPRINT_S1) && (g_fox <= SPRINT_F5) && g_callsign_sent)
		{
			g_on_the_air = FALSE;
		}
		else if((g_fox != g_fox_counter) && g_callsign_sent)    /* Turn off transmissions during minutes when this fox should be silent */
		{
			g_on_the_air = FALSE;
		}
	}
}   /* End of main loop() */

void sendMorseTone(BOOL onOff)
{
	if(!g_lastSeconds)
	{
		OCR0A = DEFAULT_TONE_FREQUENCY - g_fox_tone_offset;
		g_audio_tone_state = onOff;
	}
	else
	{
		OCR0A = DEFAULT_TONE_FREQUENCY;
		g_audio_tone_state = OFF;
	}
}

void playStartingTone(uint8_t toneFreq)
{
	if(toneFreq > 0)
	{
		OCR0A = toneFreq;
		g_audio_tone_state = ON;
	}
	else
	{
		OCR0A = DEFAULT_TONE_FREQUENCY;
		g_audio_tone_state = OFF;
	}
}

/* The compiler does not seem to optimize large switch statements correctly */
void __attribute__((optimize("O0"))) handleLinkBusMsgs()
{
	LinkbusRxBuffer* lb_buff;
	BOOL send_ack = TRUE;

	while((lb_buff = nextFullRxBuffer()))
	{
		LBMessageID msg_id = lb_buff->id;

		switch(msg_id)
		{
			case MESSAGE_RESET:
			{
				softwareReset();
			}
			break;

			case MESSAGE_OVERRIDE_DIP:
			{
				FoxType holdFox = (FoxType)g_override_DIP_switches;
				int c = (int)(lb_buff->fields[FIELD1][0]);

				if(c)
				{
					if(c == 'B')
					{
						c = BEACON;
					}
					else if(c == 'D')
					{
						char t = lb_buff->fields[FIELD2][0];

						if(t == 'S')
						{
							c = SPRINT_DEMO;
						}
						else
						{
							c = FOX_DEMO;
						}
					}
					else if(c == 'F')
					{
						c = FOXORING;
					}
					else if(c == 'C')
					{
						char t = lb_buff->fields[FIELD2][0];
						lb_buff->fields[FIELD2][1] = '\0';

						if(t == 'B')
						{
							t = '0';
						}

						if(isdigit(t))
						{
							c = CLAMP(BEACON,atoi(lb_buff->fields[FIELD2]),FOX_5);
						}
					}
					else if(c == 'S')
					{
						int x = 0;
						char t = lb_buff->fields[FIELD2][0];
						char u = lb_buff->fields[FIELD2][1];
						lb_buff->fields[FIELD2][2] = '\0';

						if(t == 'B')
						{
							x = BEACON;
						}
						else if(t == 'F')
						{
							if((u > '0') && (u < '6'))
							{
								x = SPRINT_F1 + (u - '1');
							}
						}
						else if(t == 'S')
						{
							if((u > '0') && (u < '6'))
							{
								x = SPRINT_S1 + (u - '1');
							}
							else
							{
								x = SPECTATOR;
							}
						}
						else if(u == 'F')
						{
							if((t > '0') && (t < '6'))
							{
								x = SPRINT_F1 + (t - '1');
							}
						}
						else if(u == 'S')
						{
							if((t > '0') && (t < '6'))
							{
								x = SPRINT_S1 + (t - '1');
							}
						}

						if(x != BEACON)
						{
							c = CLAMP(SPECTATOR,x,SPRINT_F5);
						}
					}
					else if(c == 'N')
					{
						char t = lb_buff->fields[FIELD2][0];

						if(t == '2')
						{
							c = NO_CODE_START_TONES_2M;
						}
						else if(t == '5')
						{
							c = NO_CODE_START_TONES_5M;
						}
						else
						{
							c = BEACON;
						}
					}
					else
					{
						c = atoi(lb_buff->fields[FIELD1]);
					}

					if((c >= BEACON) && (c < INVALID_FOX))
					{
						g_override_DIP_switches = c;
						g_fox = (FoxType)c;
						eeprom_update_byte(&ee_override_DIP_switches,g_override_DIP_switches);
						if(holdFox != g_fox)
						{
							doSynchronization();
						}
					}
				}

				sprintf(g_tempStr,"DIP=%u\n",g_override_DIP_switches);
				lb_send_string(g_tempStr,FALSE);
			}
			break;

			case MESSAGE_LEDS:
			{
				if(lb_buff->fields[FIELD1][0])
				{
					if((lb_buff->fields[FIELD1][1] == 'F') || (lb_buff->fields[FIELD1][0] == '0'))
					{
						g_enable_LEDs = FALSE;
						digitalWrite(PIN_LED,OFF);  /*  LED Off */
					}
					else
					{
						g_enable_LEDs = TRUE;
					}

					eeprom_update_byte(&ee_enable_LEDs,g_enable_LEDs);
					g_LEDs_Timed_Out = !g_enable_LEDs;
				}

				sprintf(g_tempStr,"LED:%s\n",g_enable_LEDs ? "ON" : "OFF");
				lb_send_string(g_tempStr,FALSE);
			}
			break;

			case MESSAGE_STARTTONES_ENABLE:
			{
				if(lb_buff->fields[FIELD1][0])
				{
					if((lb_buff->fields[FIELD1][1] == 'F') || (lb_buff->fields[FIELD1][0] == '0'))
					{
						g_enable_start_timer = FALSE;
					}
					else
					{
						g_enable_start_timer = TRUE;
					}

					eeprom_update_byte(&ee_enable_start_timer,g_enable_start_timer);
				}

				sprintf(g_tempStr,"STA:%s\n",g_enable_start_timer ? "ON" : "OFF");
				lb_send_string(g_tempStr,FALSE);
			}
			break;

			case MESSAGE_TRANSMITTER_ENABLE:
			{
				if(lb_buff->fields[FIELD1][0])
				{
					if((lb_buff->fields[FIELD1][1] == 'F') || (lb_buff->fields[FIELD1][0] == '0'))
					{
						cli();
						g_enable_transmitter = FALSE;
						digitalWrite(PIN_MORSE_KEY,OFF);
						sei();
					}
					else
					{
						g_enable_transmitter = TRUE;
					}

					eeprom_update_byte(&ee_enable_transmitter,g_enable_transmitter);
				}

				sprintf(g_tempStr,"TXE:%s\n",g_enable_transmitter ? "ON" : "OFF");
				lb_send_string(g_tempStr,FALSE);
			}
			break;

			case MESSAGE_GO:
			{
				doSynchronization();
				lb_send_string((char*)"Re-sync successful!\n",FALSE);
			}
			break;

			case MESSAGE_FACTORY_RESET:
			{
				initializeEEPROMVars(TRUE);
				softwareReset();
			}
			break;

			case MESSAGE_CLOCK_CAL:
			{
				if(lb_buff->fields[FIELD1][0])
				{
					uint16_t c = (uint16_t)atoi(lb_buff->fields[FIELD1]);

					if(c > 100)
					{
						g_clock_calibration = c;
						OCR1A = g_clock_calibration;
						eeprom_update_word(&ee_clock_calibration,g_clock_calibration);
					}
				}

				sprintf(g_tempStr,"Cal=%u\n",g_clock_calibration);
				lb_send_string(g_tempStr,FALSE);
			}
			break;

			case MESSAGE_SET_STATION_ID:
			{
				if(lb_buff->fields[FIELD1][0])
				{
					strcpy(g_tempStr," ");  /* Space before ID gets sent */
					strcat(g_tempStr,lb_buff->fields[FIELD1]);

					if(lb_buff->fields[FIELD2][0])
					{
						strcat(g_tempStr," ");
						strcat(g_tempStr,lb_buff->fields[FIELD2]);
					}

					if(strlen(g_tempStr) <= MAX_PATTERN_TEXT_LENGTH)
					{
						uint8_t i;
						strcpy(g_messages_text[STATION_ID],g_tempStr);
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

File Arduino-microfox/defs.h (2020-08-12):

/*
 *  MIT License
 *
 *  Copyright (c) 2020 DigitalConfections
 *
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
 *  THE SOFTWARE IS PROVIDED "AS IS", WITHOUT WARRANTY OF ANY KIND, EXPRESS OR
 *  IMPLIED, INCLUDING BUT NOT LIMITED TO THE WARRANTIES OF MERCHANTABILITY,
 *  FITNESS FOR A PARTICULAR PURPOSE AND NONINFRINGEMENT. IN NO EVENT SHALL THE
 *  AUTHORS OR COPYRIGHT HOLDERS BE LIABLE FOR ANY CLAIM, DAMAGES OR OTHER
 *  LIABILITY, WHETHER IN AN ACTION OF CONTRACT, TORT OR OTHERWISE, ARISING FROM,
 *  OUT OF OR IN CONNECTION WITH THE SOFTWARE OR THE USE OR OTHER DEALINGS IN THE
 *  SOFTWARE.
 */

#ifndef DEFS_H
#define DEFS_H

#ifndef FALSE
#define FALSE 0
#endif

#ifndef TRUE
#define TRUE !FALSE
#endif

#define COMPILE_FOR_ATMELSTUDIO7 FALSE
#define HARDWARE_EXTERNAL_DIP_PULLUPS_INSTALLED FALSE
#define CAL_SIGNAL_ON_PD3 FALSE

#if COMPILE_FOR_ATMELSTUDIO7
	#include <avr/io.h>
	#include <util/delay.h>
	#include <avr/interrupt.h>
	#define USE_WDT_RESET TRUE
#else
	#include "Arduino.h"
	#define USE_WDT_RESET FALSE
#endif // COMPILE_FOR_ATMELSTUDIO7

#ifndef HIGH
#define HIGH 0x1
#endif

#ifndef LOW
#define LOW  0x0
#endif

#ifndef INPUT
#define INPUT 0x0
#endif

#ifndef OUTPUT
#define OUTPUT 0x1
#endif

#ifndef INPUT_PULLUP
#define INPUT_PULLUP 0x3
#endif

/* #define F_CPU 16000000UL / * gets declared in makefile * / */

/******************************************************
 * Set the text that gets displayed to the user */
#define SW_REVISION "0.23"

//#define TRANQUILIZE_WATCHDOG

#define PRODUCT_NAME_SHORT "ARDF Tx"
#define PRODUCT_NAME_LONG "WB8WFK ARDF Transmitter"

/*******************************************************/

#ifndef uint16_t_defined
#define uint16_t_defined
typedef unsigned int uint16_t;
#endif

#ifndef uint32_t_defined
#define uint32_t_defined
typedef unsigned long uint32_t;
#endif

#ifndef unit8_t_defined
#define unit8_t_defined
typedef unsigned char uint8_t;
#endif

#ifndef null
#define null 0
#endif

#define PIN_MORSE_KEY 2
#define PIN_SYNC 3
#define PIN_DIP_0 4
#define PIN_DIP_1 5
#define PIN_DIP_2 6
#define PIN_UNUSED_7 7
#define PIN_UNUSED_8 8
#define PIN_AUDIO_OUT 9
#define PIN_UNUSED_10 10
#define PIN_CAL_OUT 11
#define PIN_UNUSED_12 12
#define PIN_LED 13

typedef enum {
BEACON = 0,
FOX_1,
FOX_2,
FOX_3,
FOX_4,
FOX_5,
FOX_DEMO,
FOXORING,
SPECTATOR,
SPRINT_S1,
SPRINT_S2,
SPRINT_S3,
SPRINT_S4,
SPRINT_S5,
SPRINT_F1,
SPRINT_F2,
SPRINT_F3,
SPRINT_F4,
SPRINT_F5,
SPRINT_DEMO,
NO_CODE_START_TONES_2M,
NO_CODE_START_TONES_5M,
INVALID_FOX
} FoxType;

#define MAX_CODE_SPEED_WPM 20
#define MIN_CODE_SPEED_WPM 5

typedef enum
{
	WD_SW_RESETS,
	WD_HW_RESETS,
	WD_FORCE_RESET,
	WD_DISABLE
} WDReset;


/*******************************************************/

#ifndef SELECTIVELY_DISABLE_OPTIMIZATION
	#define SELECTIVELY_DISABLE_OPTIMIZATION
#endif

/******************************************************
 * EEPROM definitions */
#define EEPROM_INITIALIZED_FLAG 0xB9 /* Never set to 0xFF */
#define EEPROM_UNINITIALIZED 0x00

#define EEPROM_STATION_ID_DEFAULT "FOXBOX"
#define EEPROM_PATTERN_TEXT_DEFAULT "PARIS|"

#define EEPROM_START_TIME_DEFAULT 0
#define EEPROM_FINISH_TIME_DEFAULT 0
#define EEPROM_EVENT_ENABLED_DEFAULT FALSE
#define EEPROM_ID_CODE_SPEED_DEFAULT 20
#define EEPROM_PATTERN_CODE_SPEED_DEFAULT 8
#define EEPROM_ON_AIR_TIME_DEFAULT 60
#define EEPROM_OFF_AIR_TIME_DEFAULT 240
#define EEPROM_INTRA_CYCLE_DELAY_TIME_DEFAULT 0
#define EEPROM_CLOCK_CALIBRATION_DEFAULT 15629
#define EEPROM_TEMP_CALIBRATION_DEFAULT 147
#define EEPROM_OVERRIDE_DIP_SW_DEFAULT 0
#define EEPROM_ENABLE_LEDS_DEFAULT 1
#define EEPROM_ENABLE_STARTTIMER_DEFAULT 1
#define EEPROM_ENABLE_TRANSMITTER_DEFAULT 1

#ifndef BOOL
	typedef uint8_t BOOL;
#endif

#ifndef Frequency_Hz
	typedef unsigned long Frequency_Hz;
#endif

#ifndef UINT16_MAX
#define UINT16_MAX __INT16_MAX__
#endif

#define OFF             0
#define ON              1
#define TOGGLE			2
#define UNDETERMINED	3

#define MIN(A,B)    ({ __typeof__(A) __a = (A); __typeof__(B) __b = (B); __a < __b ? __a : __b; })
#define MAX(A,B)    ({ __typeof__(A) __a = (A); __typeof__(B) __b = (B); __a < __b ? __b : __a; })

#define CLAMP(low, x, high) ({\
  __typeof__(x) __x = (x); \
  __typeof__(low) __low = (low);\
  __typeof__(high) __high = (high);\
  __x > __high ? __high : (__x < __low ? __low : __x);\
  })

#define MAX_TIME 4294967295L
#define MAX_UINT16 65535
#define MAX_INT16 32767
#define MIN_INT16 -32768

/* Periodic TIMER2 interrupt timing definitions */
#define TIMER2_57HZ 10
#define TIMER2_20HZ 49
#define TIMER2_5_8HZ 100
#define TIMER2_0_5HZ 1000
#define TIMER2_SECONDS_3 4283
#define TIMER2_SECONDS_2 2855
#define TIMER2_SECONDS_1 1428

#define BLINK_SHORT 100
#define BLINK_LONG 500

/* TIMER0 tone frequencies */
#define DEFAULT_TONE_FREQUENCY 0x2F
#define TONE_600Hz 0x1F
#define TONE_500Hz 0x3F
#define TONE_400Hz 0x4F

/******************************************************
 * UI Hardware-related definitions */
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

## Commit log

2020-05-24 Small Fixes
    o Fixed "Arduino.H" in defs.h
    o Updated version number to 0.1 in defs.h
    [defs.h]
2020-05-26 Major Revision
    o Numerous changes
    o New commands
    o Bug fixes
    o Temperature measurement support
    [Arduino-microfox.ino, defs.h, linkbus.h]
2020-05-26 New Folder
    Created a folder to hold the Arduino script. This should allow the project to build under Arduino IDE without the user needing to create a new folder.
2020-05-27 Clean-up and Bug Fix
    o Refactored global variable names.
    o Corrected Morse code timing.
    o Fixed an error affecting demo mode.
    [Arduino-microfox.ino, defs.h, linkbus.h]
2020-05-29 Major Changes
    o Integrated morse.cpp and morse.h into the project along with nacessary changes to make those files work correctly.
    o Various bug fixes
    o Reduced RAM memory footprint
    [Arduino-microfox.ino, defs.h, linkbus.h]
2020-05-29 Ver 0.3 - Minor Fixes and Feature Set
    o Fixed a bug that prevented the SPD settings from getting saved to EEPROM.
    o Added a temperature calibration value that gets saved to EEPROM.
    o Temp calibration gets set using > TEM C <###> command, where ### is tenths of a degree and can be positive or negative value.
    o Added comments
    o Style and syntax fixes
    o Added a time-since-reset seconds counter that could be used to incorporate delayed start, or shut-off time features.
    [Arduino-microfox.ino, defs.h, linkbus.h]
2020-05-30 Version 0.4
    o Fixes a problem with v0.3 in which Arduino changes the default values of Timer 2 registers.
    o Turns off 30-second code speed-up for BEACON and Foxoring modes.
    [Arduino-microfox.ino]
2020-05-30 Fixes an Oops in Version 0,4
    o Didn't update version number for version 0.4. This corrects that.
    o Also increments the EEPROM flag.
    [defs.h]
2020-05-30 Version 0.5
    o Clock calibration and station ID no longer get erased by a factory reset:
    The only way to set these values is using the CAL and ID serial commands.
    They still get initialized on an erased EEPROM, but never thereafter.
    o MIT license added to all files.
    [Arduino-microfox.ino, defs.h, linkbus.h]
2020-05-30 Buffer Overflow Fixed
    o Adjusts the size of the serial transmit buffer to accommodate the largest string being sent.
    o Updated version to 0.6
    [defs.h, linkbus.h]
2020-05-31 Fix for g_clock_calibration
    o Moved initializeEEPROMVars() back to the top of setup() to ensure g_clock_calibration gets read before first use.
    [Arduino-microfox.ino, defs.h]
2020-05-31 Ver 0.7
    o Serial TTY communications improvements to fix backspace bugs and prevent the user from overflowing buffers.
    [Arduino-microfox.ino, defs.h, linkbus.h]
2020-06-02 Ver 0.8
    o Added support for Sprint. Sprint fox behavior is available only when using the serial port "DIP" command. Physical DIP switches work the same as before.
    o Minor cleanup of comments and unneeded variables.
2020-06-04 Ver 0.9.1
    o Set the audio output to Pin 9.
2020-06-06 Ver 0.10
    o Added hardware watchdog support. Mostly to provide more reliable resets for the RST command.
    [Arduino-microfox.ino, defs.h]
2020-06-09 Added Hardware Documents
    Hardware folder
    Schematic document
    Gerber folder
    Zipped Gerber files
2020-06-14 Version 0.11
    o Adds optional compile for external port pin pull-ups. When the HARDWARE_EXTERNAL_DIP_PULLUPS_INSTALLED is set to FALSE (default) the software will turn on the internal port pin pull-ups prior to reading DIP and SYNC pins. Those pins will then be set to outputs (LOW) after all pins have been read, to save power.
    o Fixes a bug that prevented the FAC command from resetting the time calibration (CAL) and callsign (ID) settings.
    o Reverses the logic of DIP pins so that ON corresponds to "1".
    o Turned off the OC0A pin toggle when audio output is active. Only pin 9 is audio output now.
    o Minor cleanup and formatting changes
    [Arduino-microfox.ino, defs.h]
2020-06-14 Version 0.12
    The > GO serial command can now be used anytime to re-sync the transmitter, not just right after power-up
2020-06-16 Version 0.13
    o Synchronization using the hardware sync pin can now be performed at any time, so long as the sync pin is enabled.
    o The sync pin is enabled from power up, but gets disabled after the first transmitter cycle: (5 mins for Classic, 1 min for Sprint)
    o Sync is accomplished by pulling the sync pin low for at least one second, and then setting it high. Its internal pull-up resistor is enabled. The pin is effectively debounced in software.
    o Removed the SYN serial command, so there is now no way to disable sync using a command.
    o Fixed a few minor bugs in the TEM command.
    o Some refactoring of macro names
    [Arduino-microfox.ino, defs.h, linkbus.h]
2020-06-16 Hardware File Updates
    o Added CAD files to Hardware folder
    o Renamed schematic diagram file
    [80mbase.stl, 9vbattery_adaptor.stl, audio_jack_holder.stl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]
2020-06-23 Added HW Assembly Notes
    o Added doc to HW folder
2020-06-25 Ver 0.14
    o Added compile option to place 601Hz signal on PD3 to use for timing calibration
    o Deleted watchdog ISR.
    o Minor cleanup
2020-06-25 Cleanup
    o Fixes compile switch logic
    [Arduino-microfox.ino, defs.h]
2020-06-25 Update Assembly Notes.pdf
2020-06-30 Ver 0.15
    o Moved calibration output signal to OC2A (PB3) due to issues getting the signal to appear on OC2B.
    [Arduino-microfox.ino, defs.h]
2020-07-28 Ver 0.17
    Fixes these two minor bugs:
    o When start tones were turned off, the audio tone output would be silenced during the time that the start tone sequence would have played. The key output pin still functioned as intended.
    o Start tones had a 5-minute interval if the transmitter were set to function as a Sprint spectator beacon, instead of a more appropriate 2-minute interval.
    [Arduino-microfox.ino, defs.h]
2020-08-10 Version 0.18
    o Modes were added to allow the start tones to play without Morse code being sent between starting intervals. Both 2-minute and 5-minute silent starts are supported. The transmitter is not keyed in these modes.
    o Setting the DIP value in software applies the new DIP value immediately without a reset.
    o The LED (if enabled) is disabled after the first cycle completes, to save power.
    o Unused watchdog timer functionality was deleted.
    [Arduino-microfox.ino, defs.h]
2020-08-11 Version 0.19
    . Added the TXE command to enable/disable the transmitter. This turns off the Key output, but audio tones and LED continue to function as normal.
2020-08-11 Ver 0.20
    o Corrects a minor bug that caused the tone output to shift to the next fox tone pitch ~100ms too soon.
    [Arduino-microfox.ino, defs.h]
2020-08-12 Ver 0.21
    o Corrects several errors that prevented the DIP switch from being read correctly after a sync.
    [Arduino-microfox.ino, defs.h]
2020-08-12 Ver 0.22
    o Fixes a bug that allowed CAL and ID values to be overwritten after a software installation applies new EEPROM settings.
    o Fixes a bug that allowed the LED to be stuck in the ON state after turning off LEDs with the LED command.
    [Arduino-microfox.ino, defs.h]
2020-08-12 Ver 0.23
    o Major redesign of EEPROM logic. Now all settings will generally be saved between software updates. Running Ver. 0.23 will corrupt existing settings. Run FAC command after installing, then reset all transmitter settings.
    [Arduino-microfox.ino, defs.h]
